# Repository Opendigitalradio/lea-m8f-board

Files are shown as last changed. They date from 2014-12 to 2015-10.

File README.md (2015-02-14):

This repository contains a KiCAD project for a Ettus USRP B200-compatible
GPSDO that uses the u-blox LEA-M8F module.

It requires a modified UHD, because the reference clock output of the LEA-M8F is
30.72MHz.

This design is published under a Creative Commons CC-BY-SA licence, see
LICENCE.txt for details.

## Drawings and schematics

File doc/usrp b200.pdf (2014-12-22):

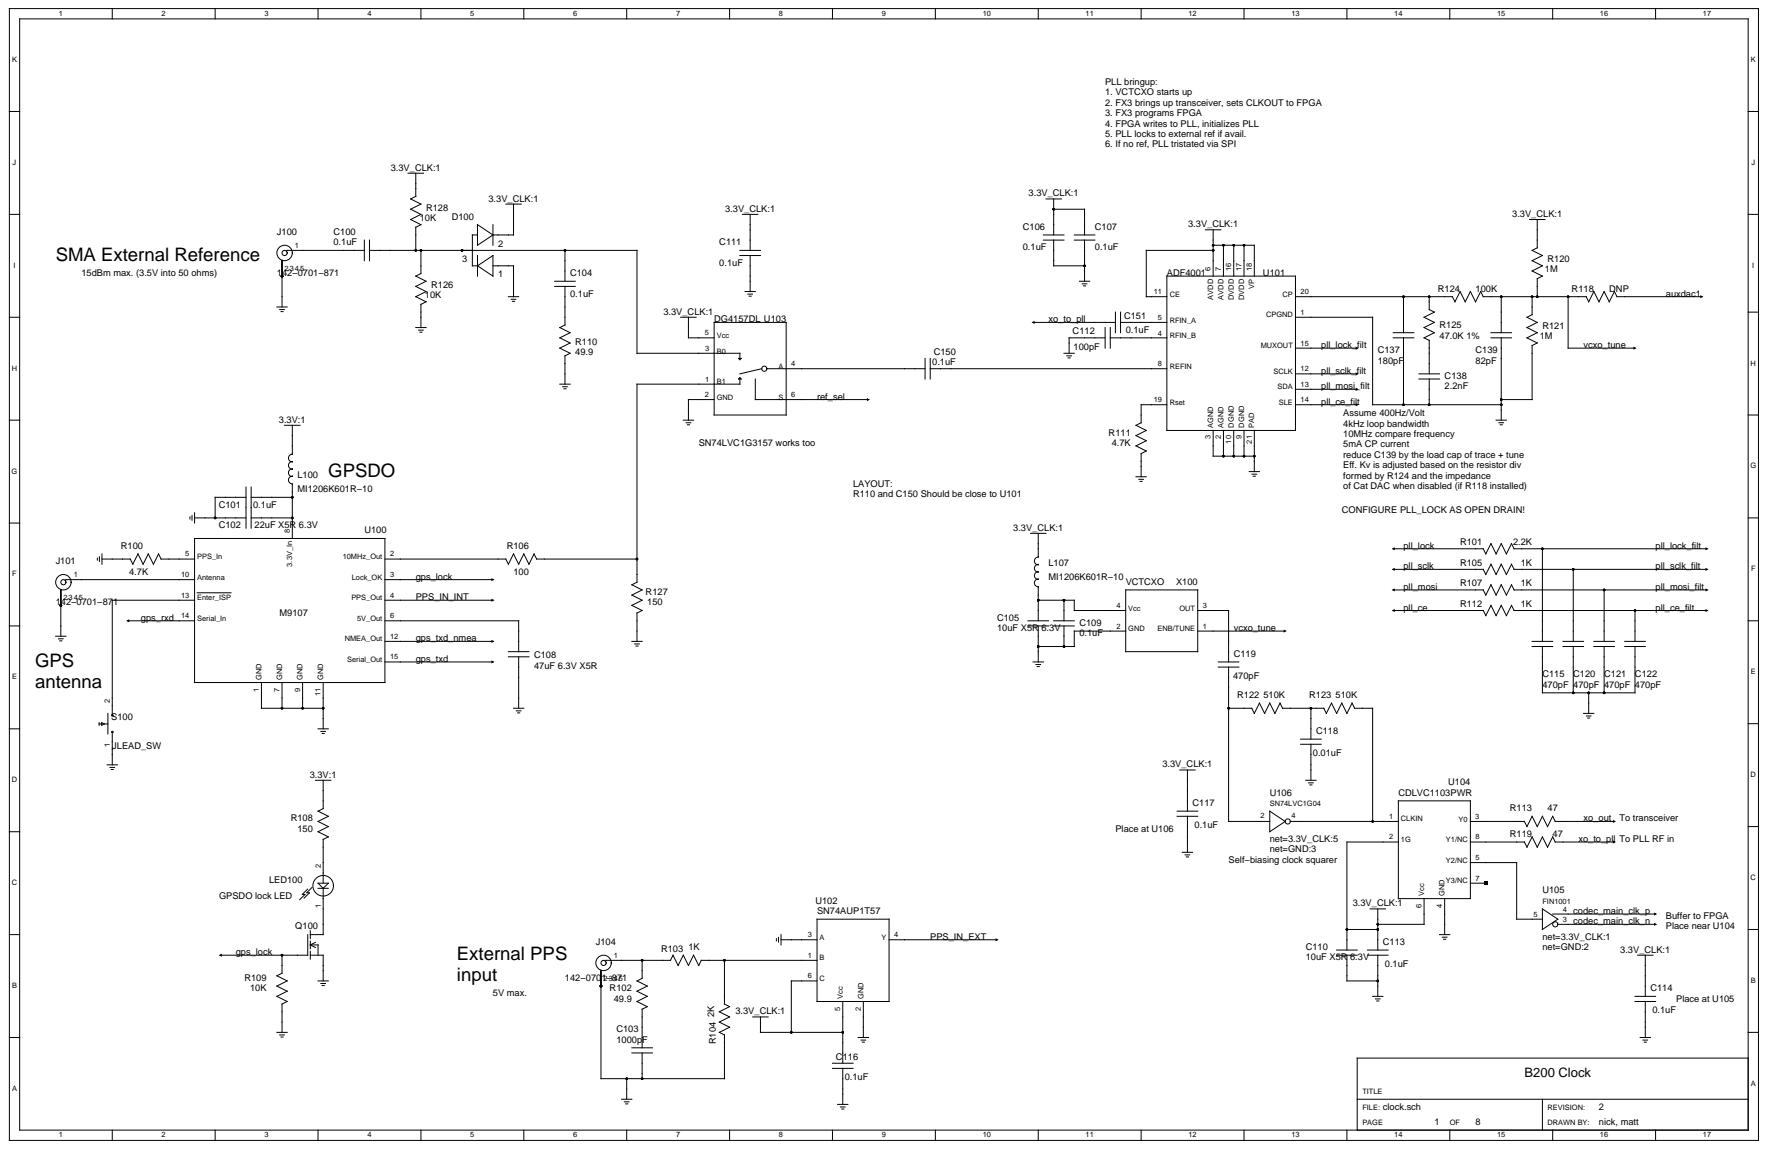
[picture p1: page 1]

PLL bringup:
1. VCTCXO starts up
2. FX3 brings up transceiver, sets CLKOUT to FPGA
3. FX3 programs FPGA
4. FPGA writes to PLL, initializes PLL
5. PLL locks to external ref if avail.
6. If no ref, PLL tristated via SPI

pll_sclk_filt
pll_mosi_filt
pll_ce_filt
Assume 400Hz/Volt
4kHz loop bandwidth
10MHz compare frequency
5mA CP current
reduce C139 by the load cap of trace + tune
Eff. Kv is adjusted based on the resistor div
formed by R124 and the impedance
of Cat DAC when disabled (if R118 installed)

LAYOUT:
R110 and C150 Should be close to U101

CONFIGURE PLL_LOCK AS OPEN DRAIN!

To transceiver
To PLL RF in

Self−biasing clock squarer

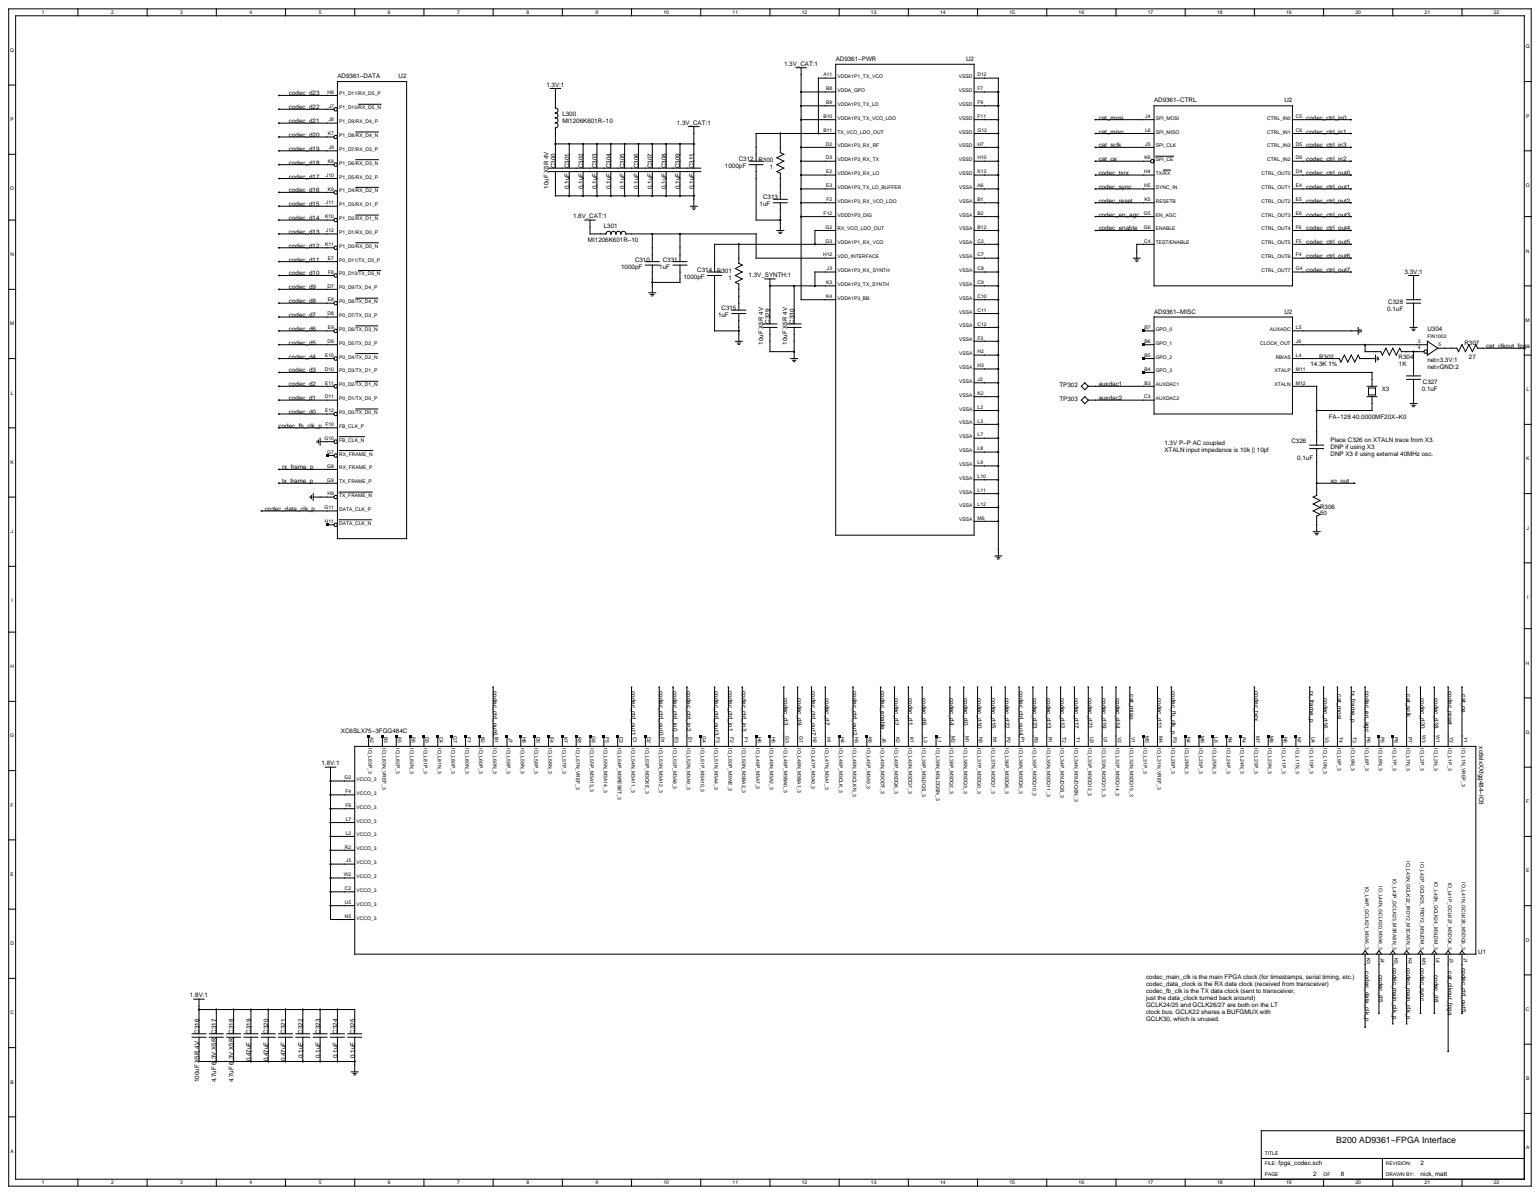
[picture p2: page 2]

1.3V P−P AC coupled
XTALN input impedance is 10k || 10pf

Place C326 on XTALN trace from X3.
DNP if using X3
DNP X3 if using external 40MHz osc.

codec_main_clk is the main FPGA clock (for timestamps, serial timing, etc.)
codec_data_clock is the RX data clock (received from transceiver)
codec_fb_clk is the TX data clock (sent to transceiver,
just the data_clock turned back around)
GCLK24/25 and GCLK26/27 are both on the LT
clock bus. GCLK22 shares a BUFGMUX with
GCLK30, which is unused.

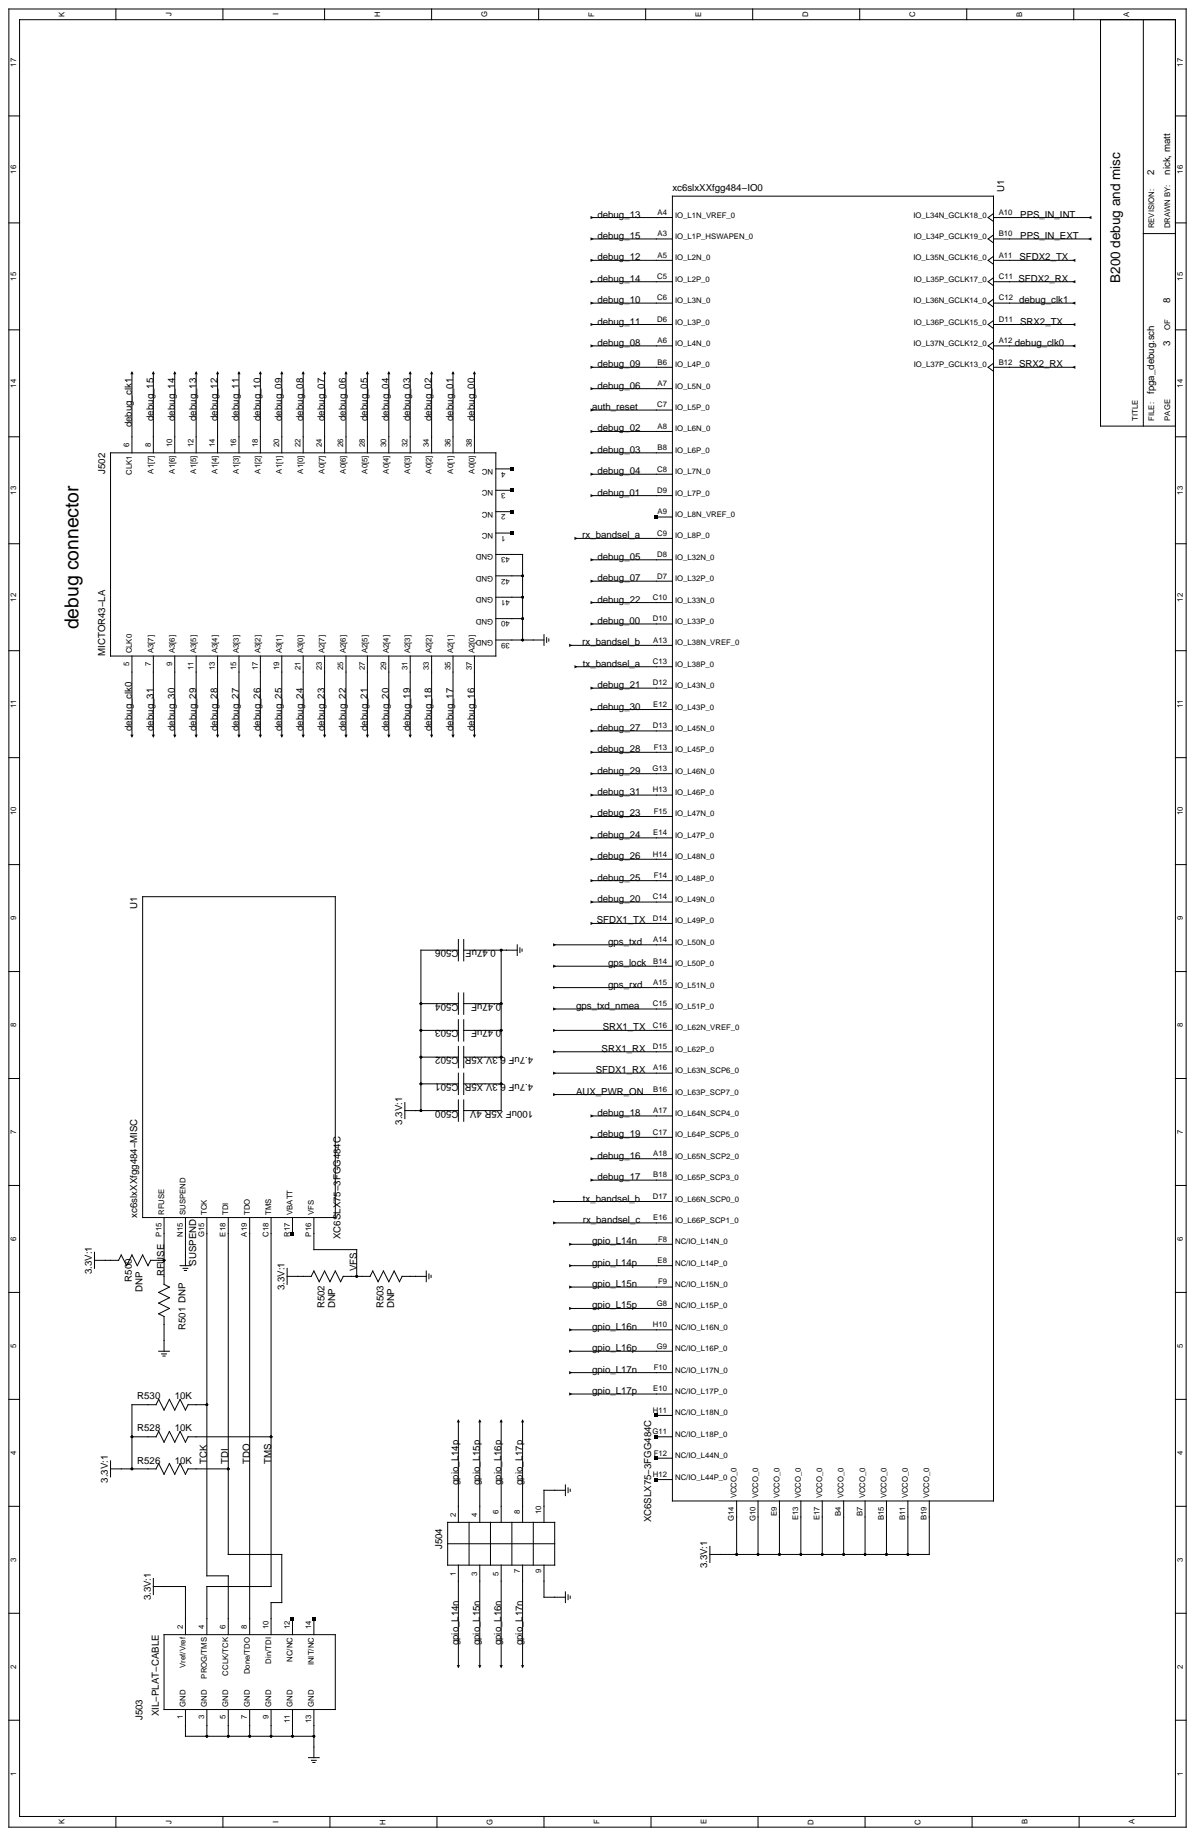
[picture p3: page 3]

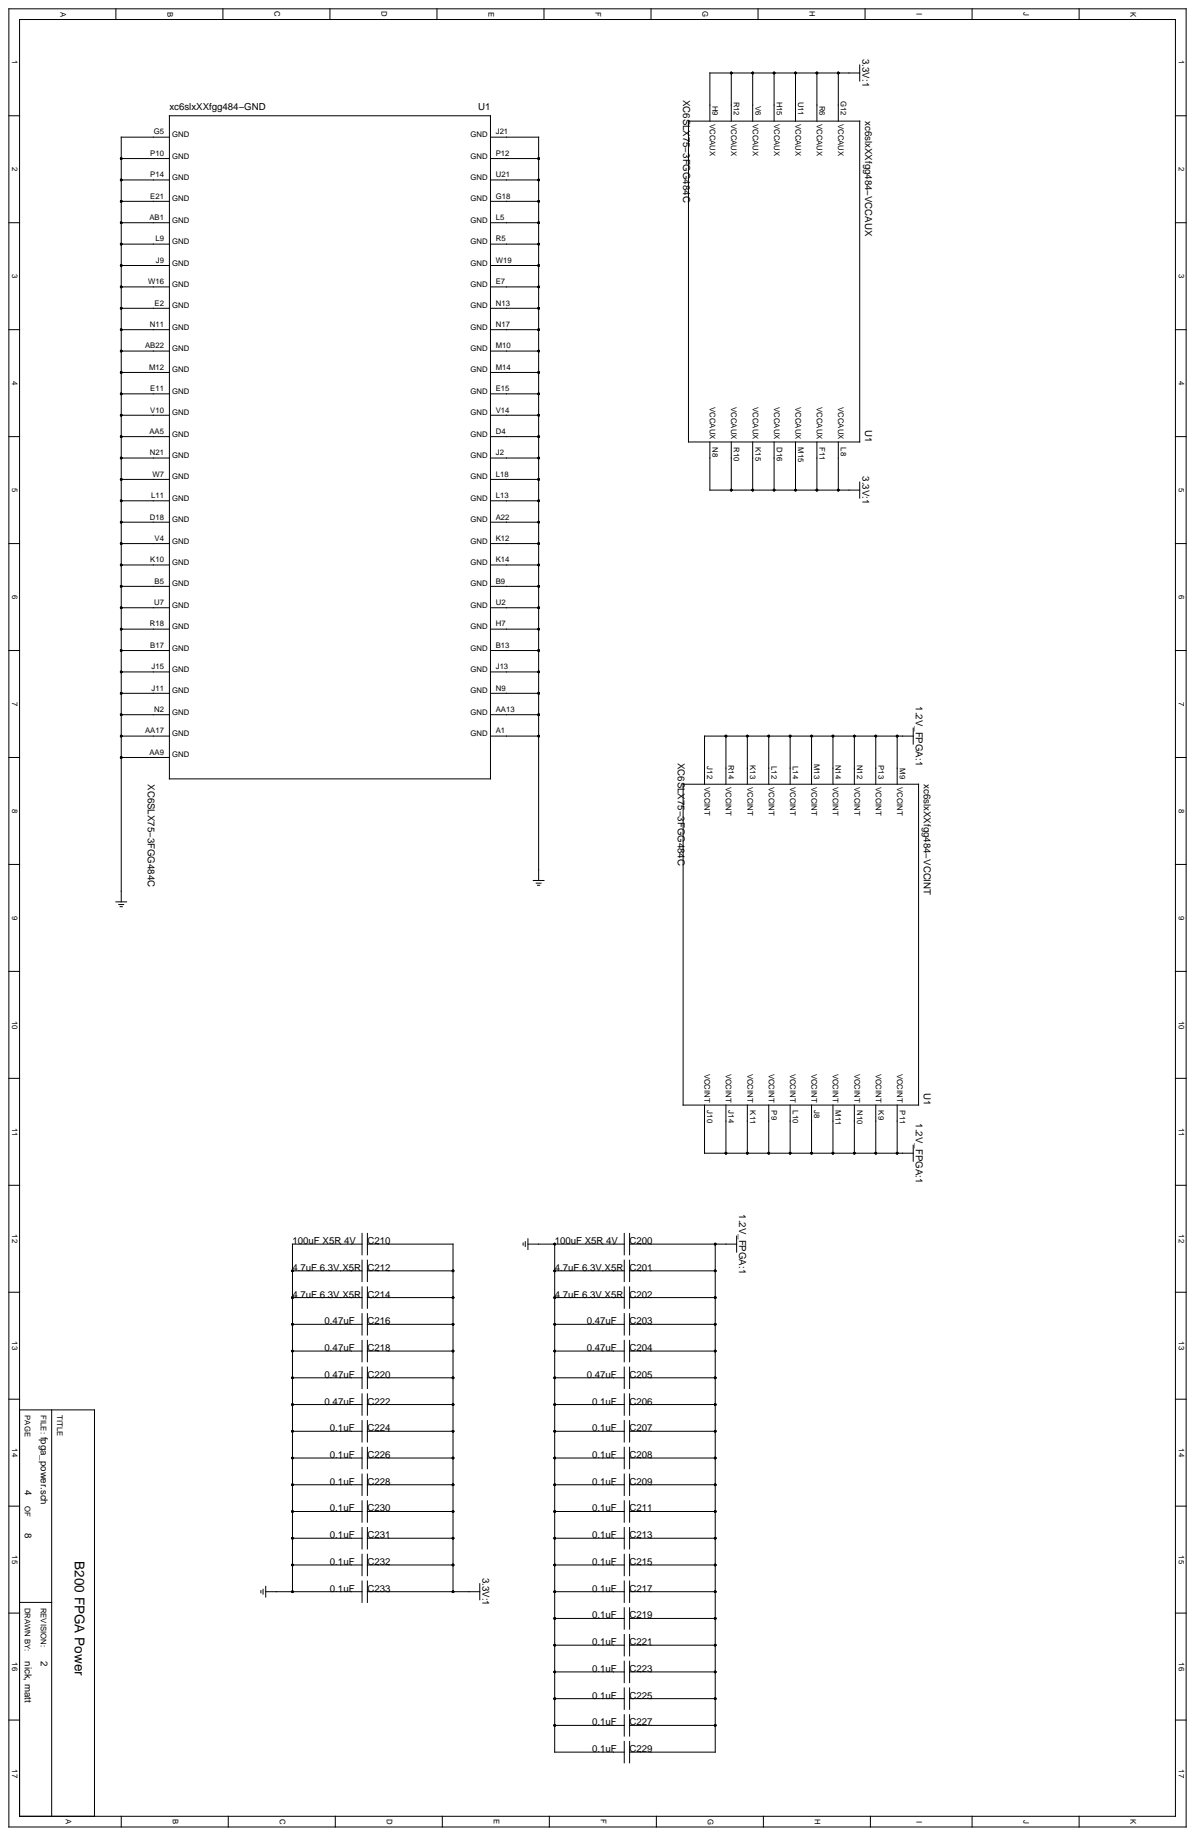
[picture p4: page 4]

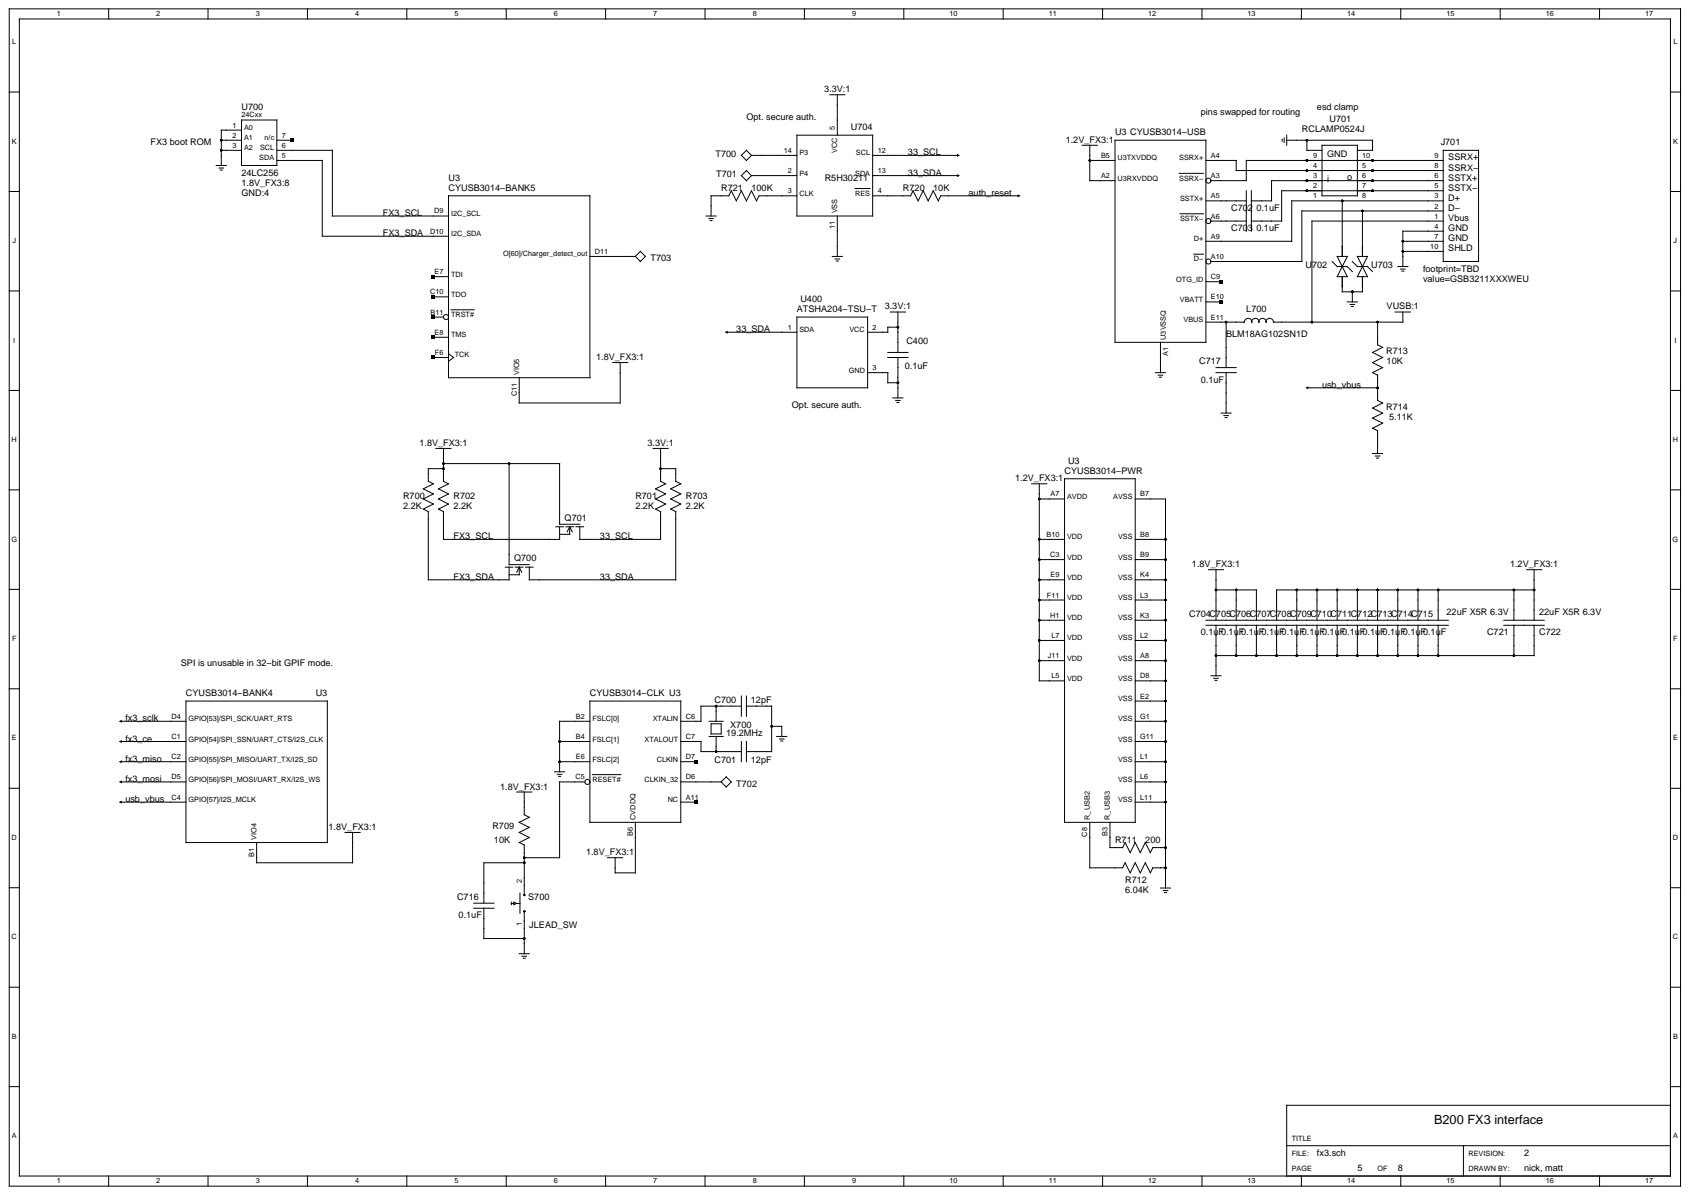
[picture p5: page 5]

pins swapped for routing

3 | i o | 6 6
2 | | 7 5

SPI is unusable in 32−bit GPIF mode.

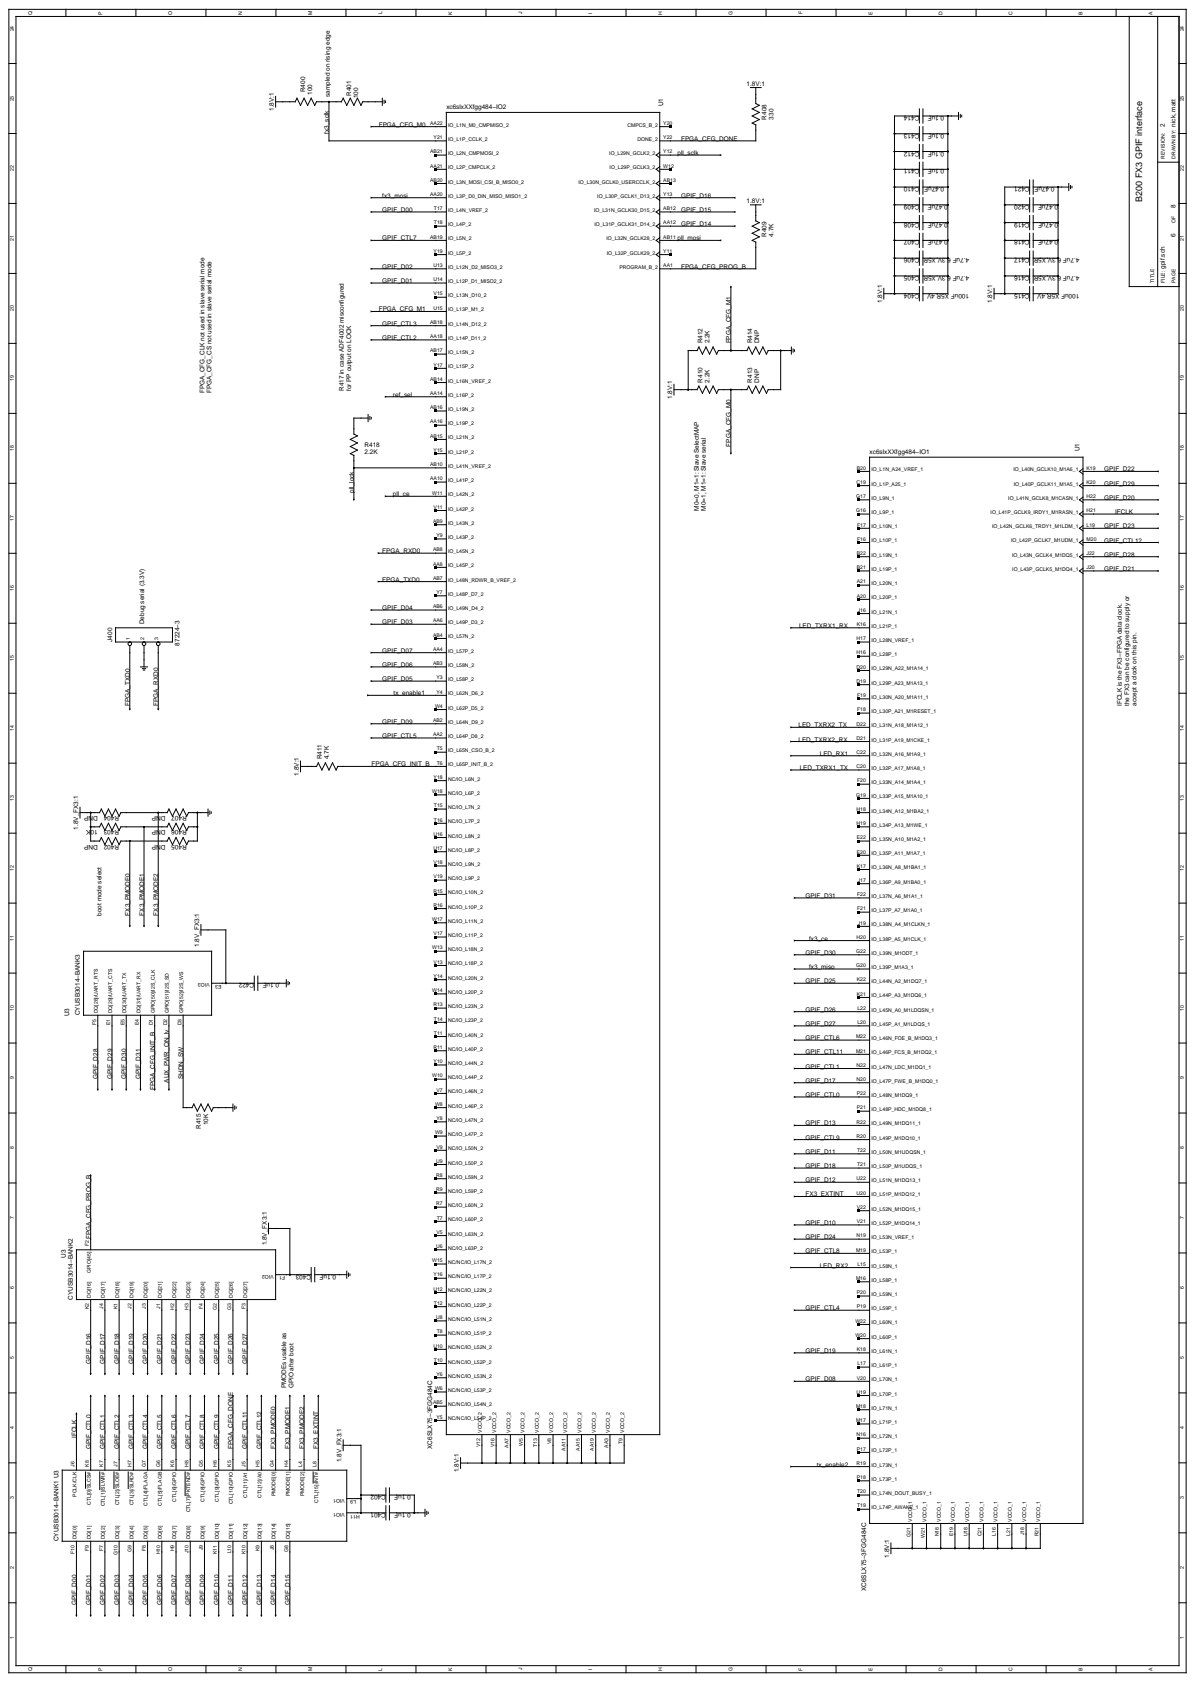
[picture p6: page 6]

sampled on rising edge

FPGA_CFG_CLK not used in slave serial mode

FPGA_CFG_CS not used in slave serial mode

for PP output on LOCK

IFCLK is the FX3−FPGA data clock.

the FX3 can be configured to supply or

accept a clock on this pin.

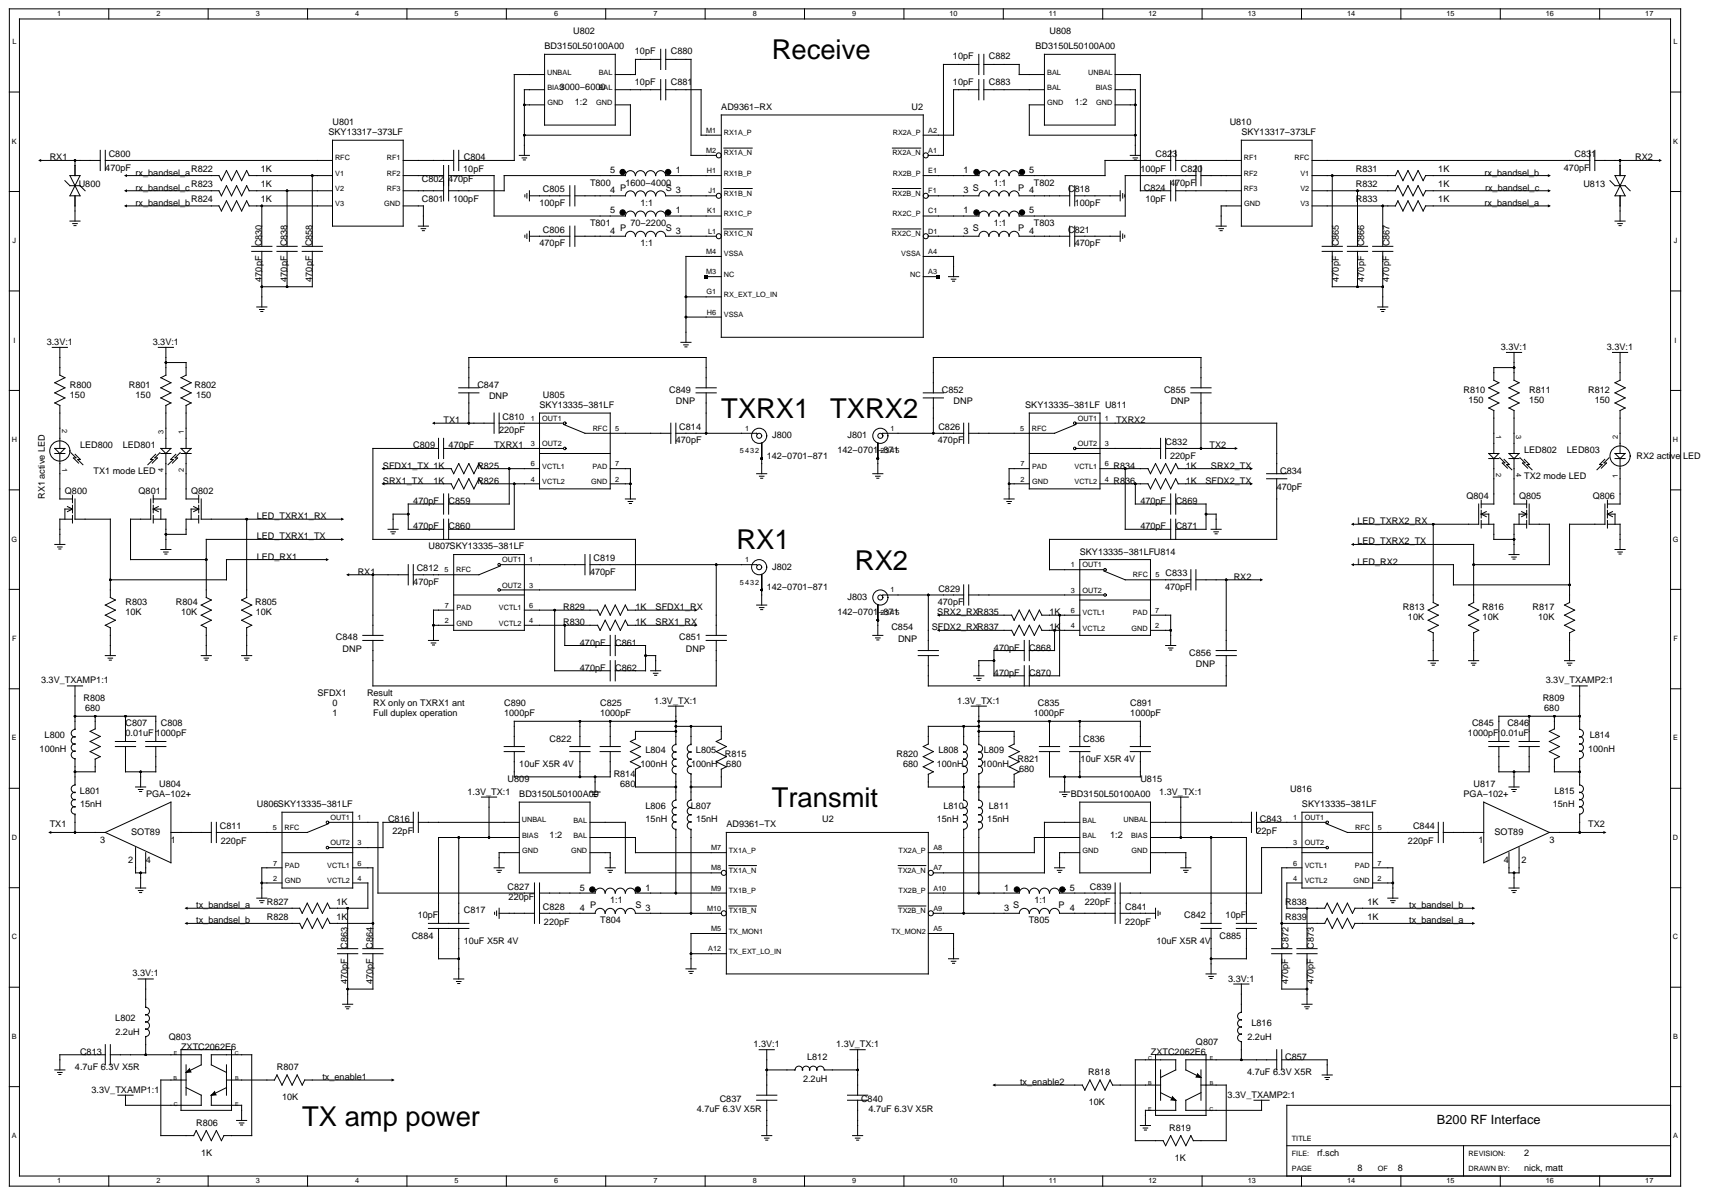
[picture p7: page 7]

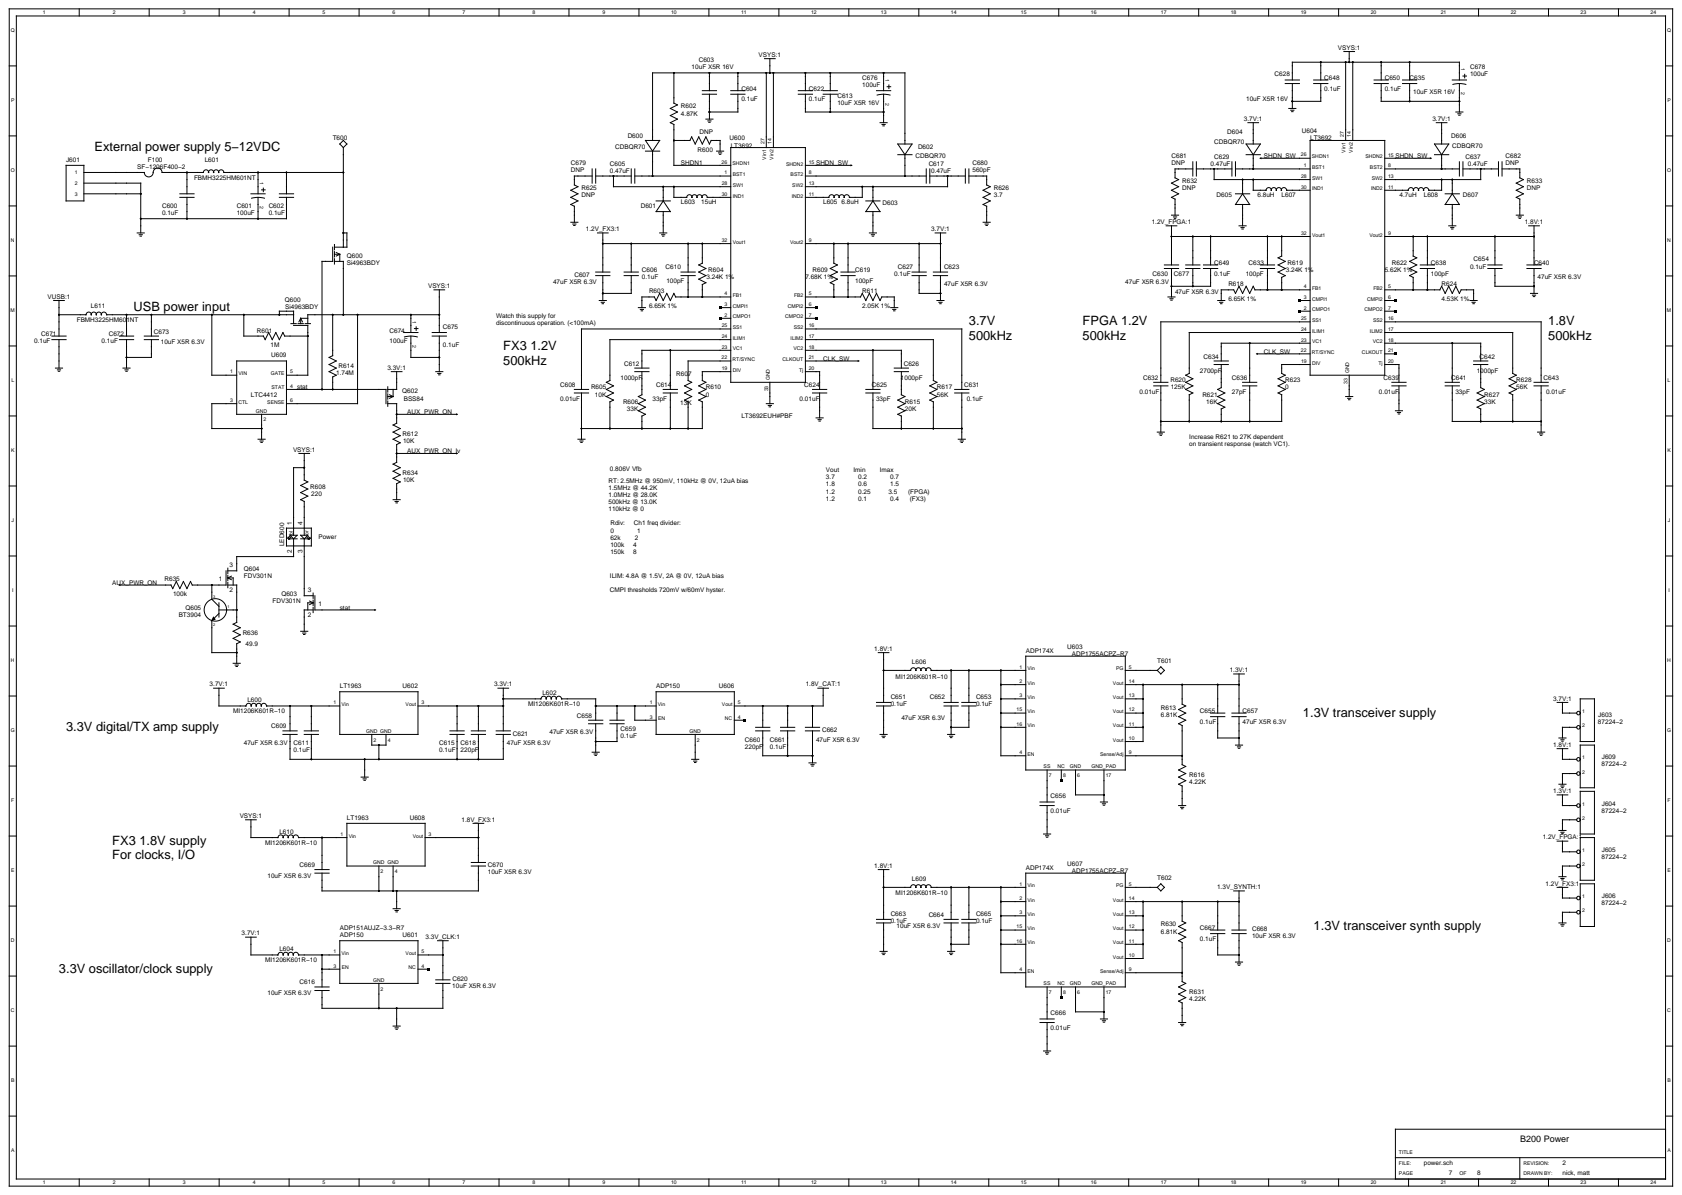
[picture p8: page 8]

Increase R621 to 27K dependent
on transient response (watch VC1).

3.3V digital/TX amp supply

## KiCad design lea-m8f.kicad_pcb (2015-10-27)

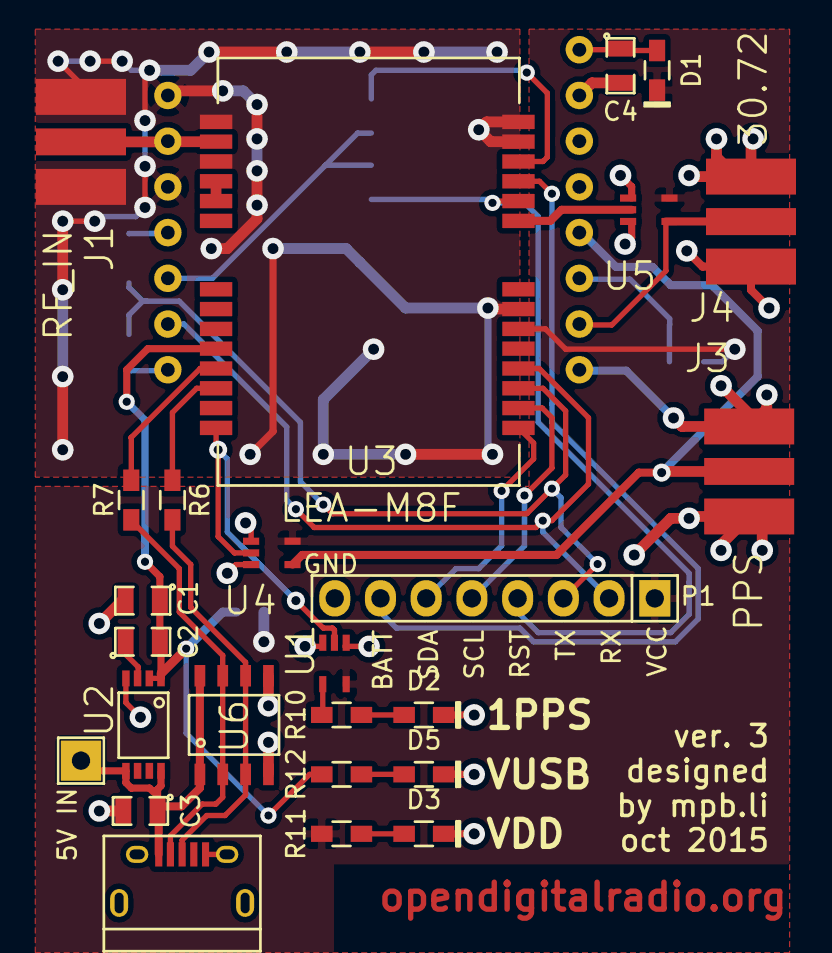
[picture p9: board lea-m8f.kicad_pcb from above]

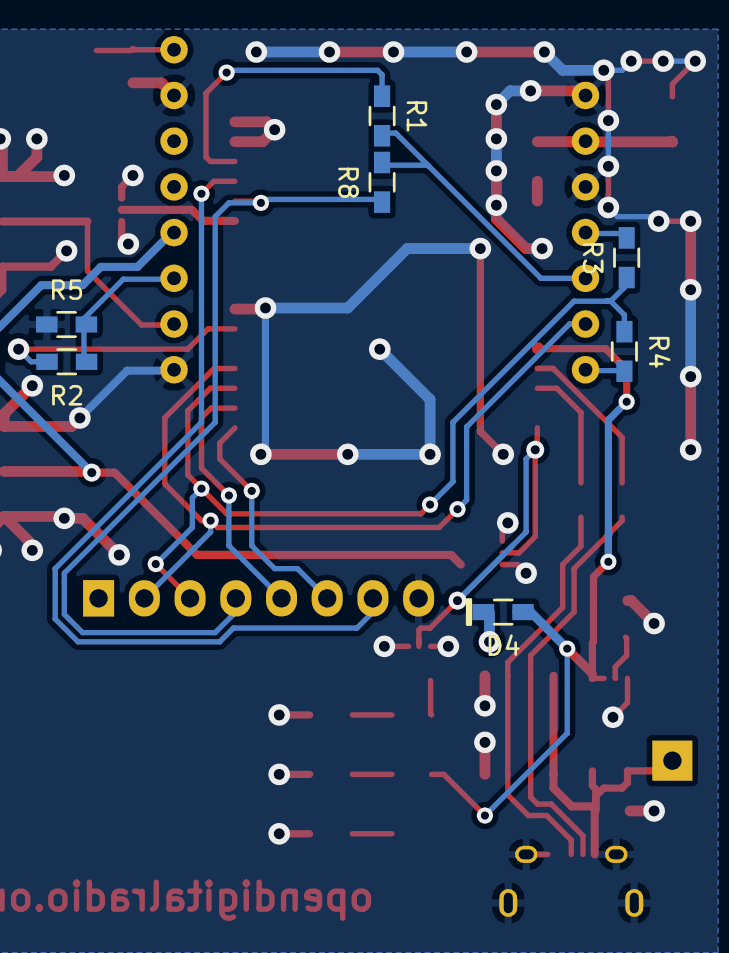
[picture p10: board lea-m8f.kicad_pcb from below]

Board: 2 copper layers, 33 parts (7 on the bottom side), 31 nets.

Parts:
C1: 10uF; SMD-0805
C2: 10nF; SMD-0805
C3, C4: 1uF; SMD-0805
CON1: USB-MICRO-B; USB_Micro-B
D1, D4: DIODESCH; Diode_0603_HandSoldering
D2: PPS; Diode_0603_HandSoldering
D3: VDD; Diode_0603_HandSoldering
D5: VUSB; Diode_0603_HandSoldering
J1: RF_IN; SMA_SIDE
J3: PPS; SMA_SIDE
J4: 30.72; SMA_SIDE
P1: CONN_01X08; Pin_Header_Straight_1x08
P2: 5V IN; Pin_Header_Straight_1x01
R1, R5, R8: DNF; R_0603_HandSoldering
R2, R3, R4: 0; R_0603_HandSoldering
R6, R7: 27; R_0603_HandSoldering
R10, R11, R12: 510; R_0603_HandSoldering
U1, U4, U5: NC7SZ125; SC70
U2: LT1962; MS8
U3: LEA-M8F; LEA
U6: USB6B1; SO-8
U100: B200_GPSDO; GPSDO_B200

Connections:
/5VUSB: C3.1, CON1.1, P2.1, U2.5, U2.8, U6.1, U6.8
/ISP_N: R1.2, R8.2, U100.13
/LOCK: R2.1, R5.2, U100.3
/M8F_PPS: U1.2, U3.28, U4.2
/PPS_BUFF: J3.2, U4.4, U100.4
/REFCLK: U3.9, U5.2
/REFCLK_BUFF: J4.2, U5.4, U100.2
/RESET_N: P1.4, R8.1, U3.10
/RF_IN: J1.2, U3.16, U100.10
/RXD: P1.2, U3.4, U100.14
/SB_N: R1.1, U3.12
/SCL: P1.5, U3.2
/SDA: P1.6, U3.1
/TXD: P1.3, R3.1, R4.1, U3.3
/VANT: U3.18, U3.19
/VBKP: P1.7, U3.11
/VDDUSB: C1.1, C2.2, D4.1, R12.1, U2.1, U2.2, U3.24
/VDD_B200: C4.1, D1.1, U100.8
GND: C1.2, C3.2, C4.2, CON1.5, CON1.6, CON1.7, CON1.8, CON1.9, D2.2, D3.2, D5.2, J1.1, J1.3, J3.1, J3.3, J4.1, J4.3, P1.8, R5.1, U1.1, U1.3, U2.4, U3.7, U3.13, U3.14, U3.15, U3.17, U4.1, U4.3, U5.1, U5.3, U6.4, U6.5, U100.1, U100.7, U100.9, U100.11
unnamed: C2.1, U2.3
unnamed: CON1.2, R7.1, U6.2, U6.7
unnamed: CON1.3, R6.1, U6.3, U6.6
unnamed: D2.1, R10.2
unnamed: D3.1, R11.1
unnamed: D5.1, R12.2
unnamed: R3.2, U100.12
unnamed: R4.2, U100.15
unnamed: R6.2, U3.26
unnamed: R7.2, U3.25
unnamed: R10.1, U1.4
VCC: D1.2, D4.2, P1.1, R2.2, R11.2, U1.5, U3.6, U4.5, U5.5

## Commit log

2014-12-20 Create lib and add footprint for LEA-M8F
    [lea-m8f.kicad_pcb, lea-m8f.sch]
2014-12-22 Add footprints and corrections
    [lea-m8f.sch]
2014-12-22 Add components to board
    [lea-m8f.kicad_pcb, lea-m8f.sch]
2015-01-09 Start place and route
    [lea-m8f.kicad_pcb, lea-m8f.sch]
2015-01-10 More routing
    [lea-m8f.kicad_pcb, lea-m8f.sch]
2015-01-10 Check what happens with polygon pours
    [lea-m8f.kicad_pcb]
2015-01-11 do zone via stitch, correct footprints, revise board outline
    [lea-m8f.kicad_pcb, lea-m8f.sch]
2015-01-11 Correct margin on the left
    [lea-m8f.kicad_pcb, lea-m8f.sch]
2015-01-23 update PCB
    [lea-m8f.kicad_pcb]
2015-01-23 Remove UART connector and max232
    [lea-m8f.sch]
2015-01-23 update schematic
    add LEDs for power and PPS
    correct power managment (diodes)
    [lea-m8f.sch]
2015-01-23 Annotate schematic
    [lea-m8f.sch]
2015-01-23 Add text to PCB
    [lea-m8f.kicad_pcb]
2015-01-23 Correct LEA footprint, add silkscreen
    [lea-m8f.kicad_pcb]
2015-01-23 Fixed footprints and layout
    [lea-m8f.kicad_pcb]
2015-01-23 add gerber renamer script
2015-02-13 Put GND below LEA
    [lea-m8f.kicad_pcb]
2015-02-13 Update footprints
    [lea-m8f.kicad_pcb, lea-m8f.sch]
2015-02-14 Add more GND vias and move some tracks
    [lea-m8f.kicad_pcb]
2015-05-14 Some corrections, and change date on silkscreen
    [lea-m8f.kicad_pcb]
2015-10-27 Update footprint for diodes
    [lea-m8f.kicad_pcb, lea-m8f.sch]
2016-06-16 Add comments to schematic and 3V3 LDO
    [lea-m8f.sch]
